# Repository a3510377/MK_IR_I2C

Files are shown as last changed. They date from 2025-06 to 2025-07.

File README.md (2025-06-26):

# MK_IR_I2C

基於 STM32F030F4P6 所設計的紅外線感測器陣列模組，具備 I2C 通訊能力，可快速整合至各類型機器人平台與自動化設備中。模組透過 CD74HC4067 多工器讀取 QRE1113GR 感測器，並將資料經 I2C 匯流排傳送至主控板（如 Arduino 或其他 MCU）。

## 🛠️ 硬體架構

- **MCU**：STM32F030F4P6
- **感測器**：16 顆 QRE1113GR 反射式紅外線感測器
- **類比多工器**：CD74HC4067
- **I²C 介面**：Slave 模式，支援標準與高速模式（100kHz / 400kHz）
- **輸出資料**：多通道反射值，單位為 8-bit 整數
- **擴充性**：
  - 支援多模組串接（透過不同 I²C 位址）
  - 每個感測器可單獨設定門檻值與使能狀態

## 📦 軟體功能

- I²C slave 實作，可接收主機命令與回傳感測資料
- 支援動態設定感測器參數（使能/閾值）
- 感測資料自動掃描（DMA + ADC）
- 內建 LED 狀態指示

## 📋 I²C 寄存器對照表（Register Map）

| 名稱 | 地址 | 權限 | 大小 | 說明 |
| --- | ---- | --- | --- | --- |
| `REG_LED` | 0x01 | R/W (CB) | 2 bytes  | 控制自訂 LED 狀態（16-bit），自動啟用自訂控制 |
| `REG_LED_MODE_MASK` | 0x02 | R/W | 2 bytes  | LED 控制遮罩，1=自訂控制，0=由閾值自動控制 |
| `REG_READ_THRESHOLD_ONE`  | 0x13 | R (CB) | 3 bytes  | 讀取單一通道閾值，格式：`[index] → [index][LSB][MSB]` |
| `REG_WRITE_THRESHOLD_ONE` | 0x14 | W (CB) | 3 bytes  | 寫入單一通道閾值，格式：`[index][LSB][MSB]` |
| `REG_THRESHOLD_ALL` | 0x15 | R/W (CB) | 32 bytes | 一次讀/寫全部 16 通道閾值，每通道 2 bytes |
| `REG_THRESHOLD_FLAG` | 0x16 | R | 2 bytes  | 閾值比較旗標（bitmask），1=超過，0=未超過 |
| `REG_ADC_DATA` | 0x29 | R | 32 bytes | 讀取所有通道 ADC 資料（16 通道 × 2 bytes） |
| `REG_ADC_DATA00` | 0x30 | R | 2 bytes  | 通道 0 的 ADC 數值 |
| `REG_ADC_DATA01` | 0x31 | R | 2 bytes  | 通道 1 的 ADC 數值 |
| `REG_ADC_DATA02` | 0x32 | R | 2 bytes  | 通道 2 的 ADC 數值 |
| `REG_ADC_DATA03` | 0x33 | R | 2 bytes  | 通道 3 的 ADC 數值 |
| `REG_ADC_DATA04` | 0x34 | R | 2 bytes  | 通道 4 的 ADC 數值 |
| `REG_ADC_DATA05` | 0x35 | R | 2 bytes  | 通道 5 的 ADC 數值 |
| `REG_ADC_DATA06` | 0x36 | R | 2 bytes  | 通道 6 的 ADC 數值 |
| `REG_ADC_DATA07` | 0x37 | R | 2 bytes  | 通道 7 的 ADC 數值 |
| `REG_ADC_DATA08` | 0x38 | R | 2 bytes  | 通道 8 的 ADC 數值 |
| `REG_ADC_DATA09` | 0x39 | R | 2 bytes  | 通道 9 的 ADC 數值 |
| `REG_ADC_DATA10` | 0x3A | R | 2 bytes  | 通道 10 的 ADC 數值 |
| `REG_ADC_DATA11` | 0x3B | R | 2 bytes  | 通道 11 的 ADC 數值 |
| `REG_ADC_DATA12` | 0x3C | R | 2 bytes  | 通道 12 的 ADC 數值 |
| `REG_ADC_DATA13` | 0x3D | R | 2 bytes  | 通道 13 的 ADC 數值 |
| `REG_ADC_DATA14` | 0x3E | R | 2 bytes  | 通道 14 的 ADC 數值 |
| `REG_ADC_DATA15` | 0x3F | R | 2 bytes  | 通道 15 的 ADC 數值 |
| `REG_VERSION` | 0xFE | R | 2 bytes  | 固件版本號（例如 `0x0102` 表示 v1.0.2） |
| `REG_LAST_ERROR` | 0xFF | R | 1 byte | 最後錯誤代碼（讀取後自動清除） |

> 💡 **說明**：
>
> - 權限欄位：`R` = Read、`W` = Write、`CB` = 透過 callback 處理邏輯。
> - 所有資料皆為小端序（Little Endian）。

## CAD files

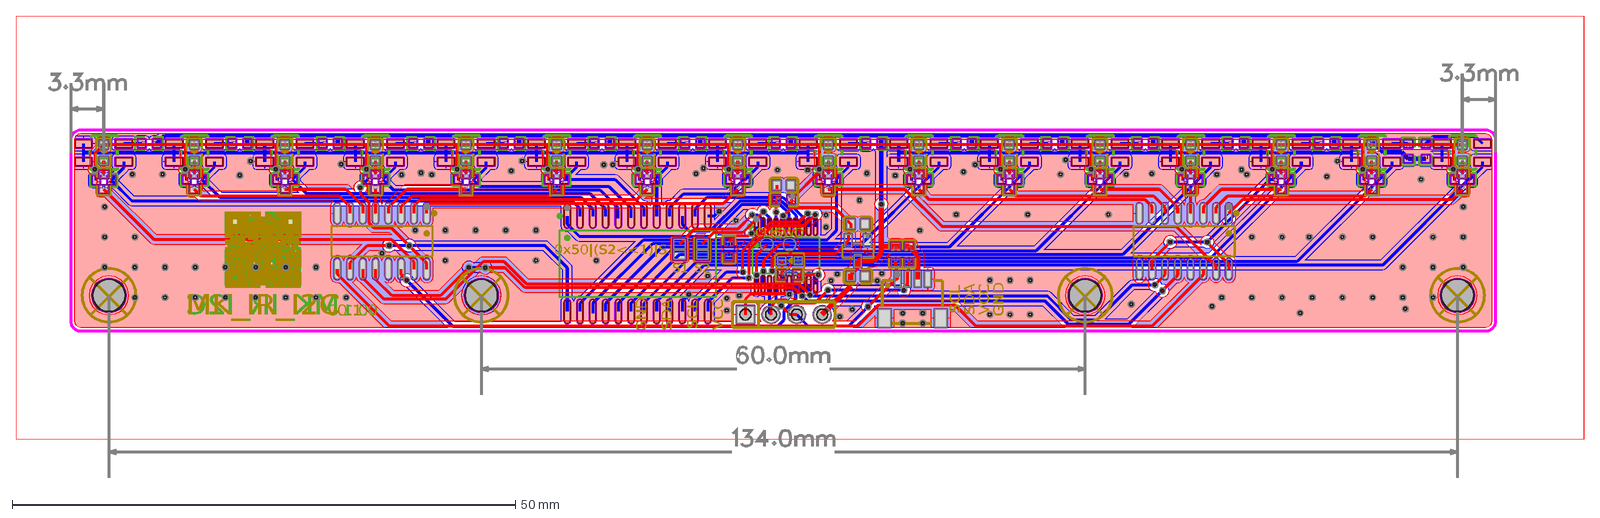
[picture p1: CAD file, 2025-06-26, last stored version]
docs/DXF_MK_IR_I2C_2025-06-17_AutoCAD2007.dxf
MK_IR_I2C
v0.1.0
GND
SDA
SCL
VCC
S2
S1
0x50|(S2<<1)|S1
CLK
SWD

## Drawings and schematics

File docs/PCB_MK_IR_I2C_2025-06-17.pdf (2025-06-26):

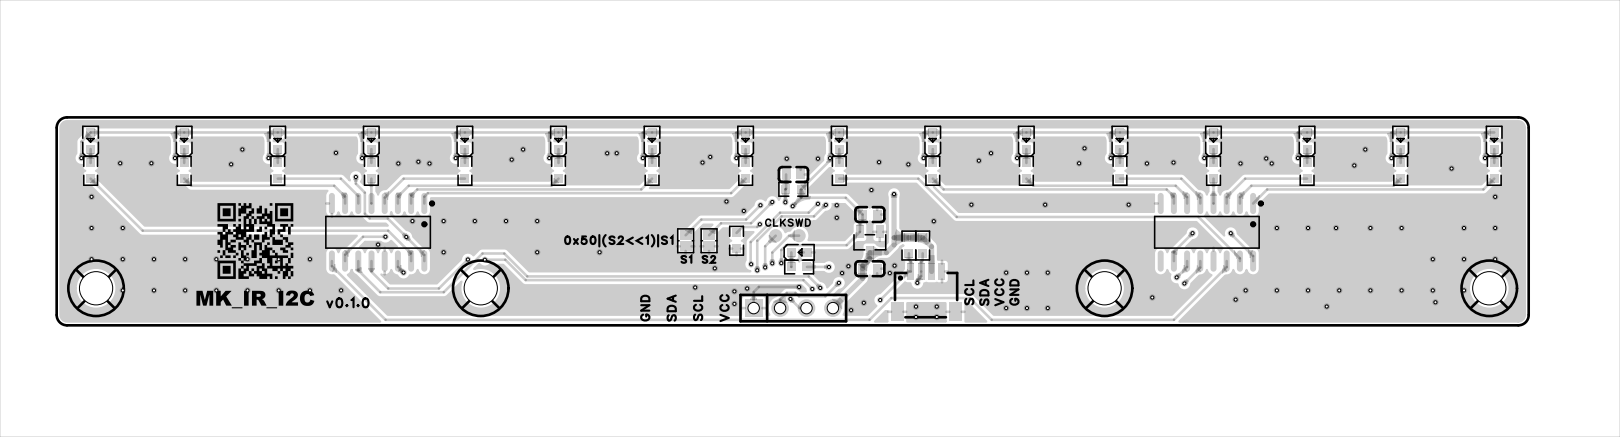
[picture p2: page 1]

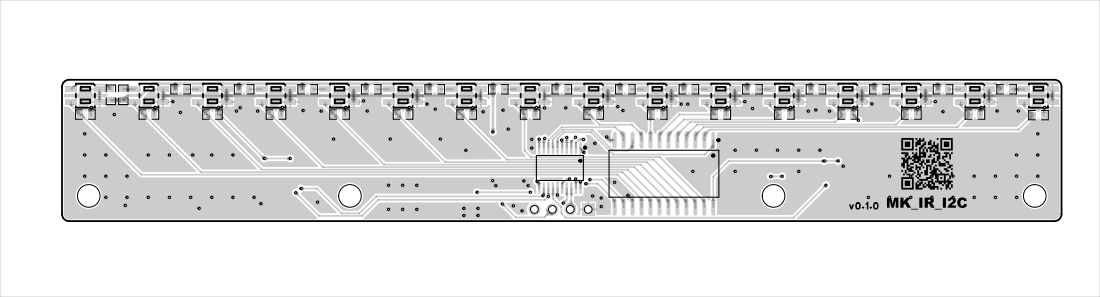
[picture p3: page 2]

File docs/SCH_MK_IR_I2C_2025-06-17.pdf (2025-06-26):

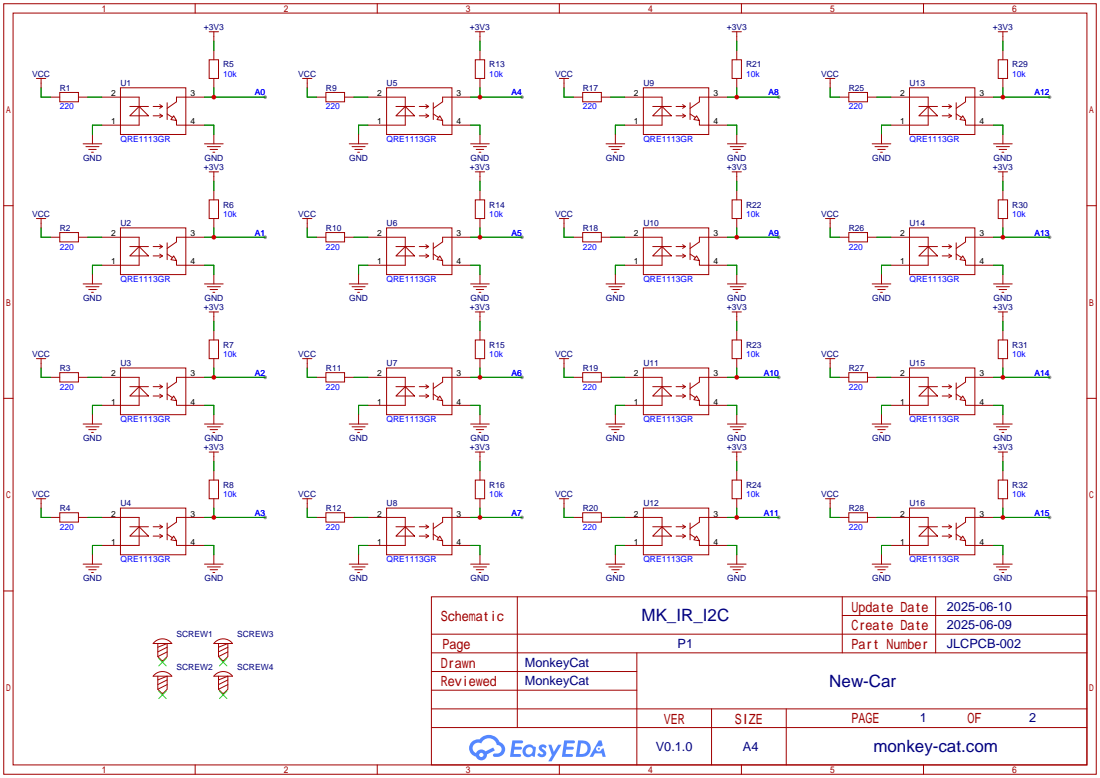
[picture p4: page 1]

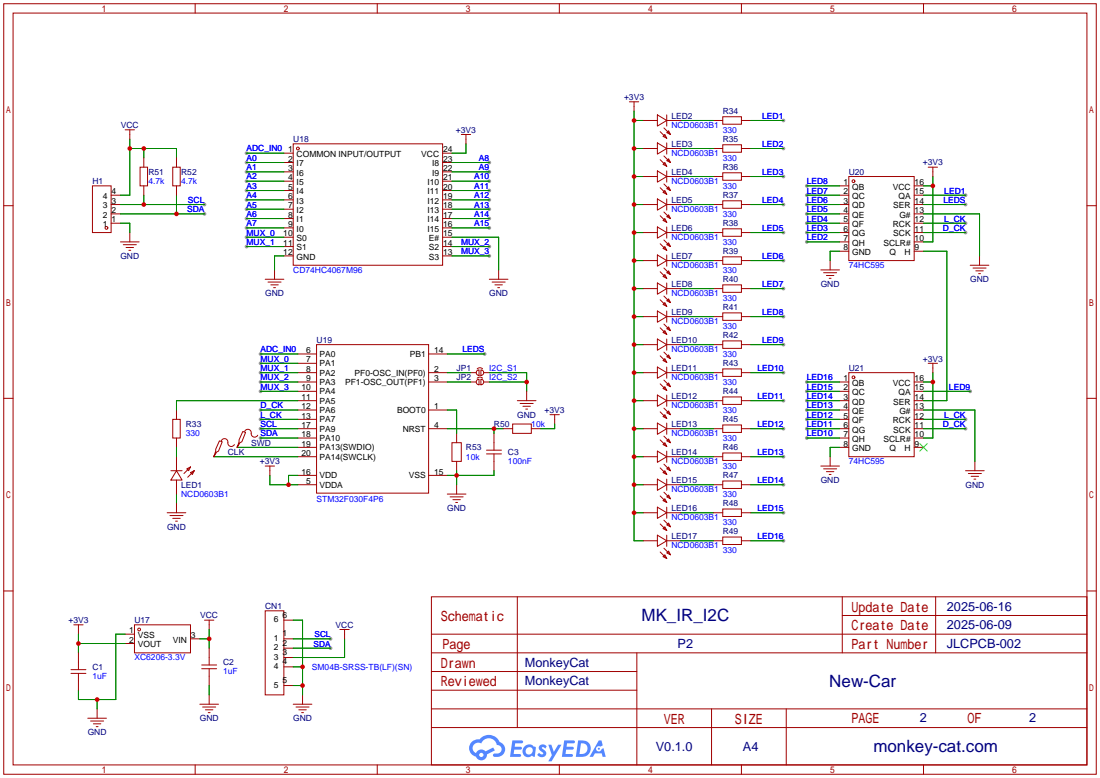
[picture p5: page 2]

SCLR# 10 SCK 11 RCK 12 G# 13 SER 14 QA 15 VCC 16

SM04B-SRSS-TB(LF)(SN)

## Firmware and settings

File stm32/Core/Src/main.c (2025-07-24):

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
/* Includes ------------------------------------------------------------------*/
#include "main.h"
#include "adc.h"
#include "dma.h"
#include "i2c.h"
#include "gpio.h"

/* USER CODE BEGIN Includes */
#include "i2c_slave.h"
#include "status.h"
/* USER CODE END Includes */

/* USER CODE BEGIN PD */
#define I2C_TX_BUF_SIZE 32
#define I2C_RX_BUF_SIZE 4
/* USER CODE END PD */

/* USER CODE BEGIN PM */
#define GPIO_SET(GPIOx, PinMask) ((GPIOx)->BSRR = (PinMask))
#define GPIO_CLR(GPIOx, PinMask) ((GPIOx)->BRR = (PinMask))
// #define GPIO_CLR(GPIOx, PinMask) ((GPIOx)->BSRR = ((uint32_t)(PinMask) <<
// 16))

/* USER CODE END PM */


void SystemClock_Config(void);
/* USER CODE BEGIN PFP */
void update_LED(void);
/* USER CODE END PFP */

/* USER CODE BEGIN 0 */
static int rx_busy_counter = 0;

volatile uint8_t last_error        = 0;
volatile uint16_t led_mode_mask    = 0;
volatile uint16_t custom_leds_data = 0;               // custom led value
volatile uint16_t threshold_flag   = 0;               // threshold result
volatile uint16_t thresholds[16]   = {0};             // led threshold
volatile uint16_t leds_data = 0, last_leds_data = 0;  // led value
volatile uint16_t mux_data[16] = {0};                 // adc value

volatile uint8_t mux_index       = 0;  // current mux index
volatile uint32_t adc_dma_buffer = 0;  // current adc value

static uint32_t last_update_time          = 0;
static volatile uint8_t updated_mux_index = 0;
/* USER CODE END 0 */

/**
 * @brief  The application entry point.
 * @retval int
 */
int main(void) {
  /* MCU Configuration--------------------------------------------------------*/

  /* Reset of all peripherals, Initializes the Flash interface and the Systick. */
  HAL_Init();

  /* Configure the system clock */
  SystemClock_Config();

  /* Initialize all configured peripherals */
  MX_GPIO_Init();
  MX_DMA_Init();
  MX_I2C1_Init();
  MX_ADC_Init();
  /* USER CODE BEGIN 2 */
  if (HAL_ADC_Start_DMA(&hadc, (uint32_t *)&adc_dma_buffer, 1) != HAL_OK) {
    Error_Handler();
  }
  if (I2C_begin() != HAL_OK) {
    Error_Handler();
  }

  update_LED();
  set_default_status();
  /* USER CODE END 2 */

  /* Infinite loop */
  /* USER CODE BEGIN WHILE */
  while (1) {
    uint32_t current_time = HAL_GetTick();
    if (current_time - last_update_time >= 1) {
      if (HAL_I2C_GetState(&hi2c1) == HAL_I2C_STATE_BUSY_RX_LISTEN) {
        rx_busy_counter++;

        if (rx_busy_counter > I2C_RX_BUSY_CNTR) {
          HAL_I2C_DisableListen_IT(&hi2c1);
          HAL_I2C_DeInit(&hi2c1);
          HAL_I2C_Init(&hi2c1);
          HAL_I2C_EnableListen_IT(&hi2c1);
          rx_busy_counter = 0;
        }
      } else rx_busy_counter = 0;

      if (last_leds_data != leds_data) {
        update_LED();
      }
    }

    if (mux_index == updated_mux_index) {
      mux_index = (mux_index + 1) % 16;

      // eq: GPIOA->BSRR = (0x0f << (16 + 1)) | ((mux_index & 0x0f) << 1);
      GPIOA->BSRR = 0x1e0000 | ((mux_index & 0x0f) << 1);

      for (int i = 0; i < 10; i++) __NOP();

      HAL_ADC_Start_DMA(&hadc, (uint32_t *)&adc_dma_buffer, 1);
    }

    update_status();
    /* USER CODE END WHILE */

    /* USER CODE BEGIN 3 */
  }
  /* USER CODE END 3 */
}

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
/* USER CODE BEGIN 4 */
void HAL_ADC_ConvCpltCallback(ADC_HandleTypeDef *hadc) {
  if (hadc->Instance == ADC1) {
    uint16_t value      = adc_dma_buffer;
    mux_data[mux_index] = value;

    uint16_t mask = 1 << mux_index;
    if (value > thresholds[mux_index]) threshold_flag |= mask;
    else threshold_flag &= ~mask;

    if (led_mode_mask & mask) {
      if (custom_leds_data & mask) leds_data |= mask;
      else leds_data &= ~mask;
    } else {
      if (threshold_flag & mask) leds_data |= mask;
      else leds_data &= ~mask;
    }

    updated_mux_index = mux_index;
  }
}

/** to display leds (HC595) */
void update_LED() {
  GPIO_CLR(L_CK_GPIO_Port, L_CK_Pin);
  for (uint8_t i = 0; i < 16; i++) {
    if (leds_data & (1 << i)) GPIO_SET(LEDS_GPIO_Port, LEDS_Pin);
    else GPIO_CLR(LEDS_GPIO_Port, LEDS_Pin);

    GPIO_SET(D_CK_GPIO_Port, D_CK_Pin);
    GPIO_CLR(D_CK_GPIO_Port, D_CK_Pin);
  }
  GPIO_SET(L_CK_GPIO_Port, L_CK_Pin);
  GPIO_CLR(L_CK_GPIO_Port, L_CK_Pin);

  last_leds_data = leds_data;
}
/* USER CODE END 4 */
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


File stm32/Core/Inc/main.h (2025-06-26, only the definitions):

#define I2C_S1_Pin GPIO_PIN_0
#define I2C_S1_GPIO_Port GPIOF
#define I2C_S2_Pin GPIO_PIN_1
#define I2C_S2_GPIO_Port GPIOF
#define MUX_0_Pin GPIO_PIN_1
#define MUX_0_GPIO_Port GPIOA
#define MUX_1_Pin GPIO_PIN_2
#define MUX_1_GPIO_Port GPIOA
#define MUX_2_Pin GPIO_PIN_3
#define MUX_2_GPIO_Port GPIOA
#define MUX_3_Pin GPIO_PIN_4
#define MUX_3_GPIO_Port GPIOA
#define STATUS_Pin GPIO_PIN_5
#define STATUS_GPIO_Port GPIOA
#define D_CK_Pin GPIO_PIN_6
#define D_CK_GPIO_Port GPIOA
#define L_CK_Pin GPIO_PIN_7
#define L_CK_GPIO_Port GPIOA
#define LEDS_Pin GPIO_PIN_1
#define LEDS_GPIO_Port GPIOB

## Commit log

2025-06-26 Update README with detailed hardware and register info
    Expanded the README to include a comprehensive description of the MK_IR_I2C module, its hardware architecture, software features, and a detailed I2C register map. This provides clearer guidance for i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
2025-06-26 Add callback for last_error register and refactor types
    Introduced a callback function for the last_error register to reset the error after reading. Refactored ValueType_t and reg_t struct formatting for consistency. Updated README to remove outdated note about LED and threshold data structure.
    [registers.c]
2025-06-26 feat i2c addr from S1 and S2
2025-06-27 change dir
    [DXF_MK_IR_I2C_2025-06-17_AutoCAD2007.dxf]
2025-07-24 Remove IWDG support and add MK_IR_I2C library
    Deleted IWDG-related source, headers, and driver files, and disabled HAL_IWDG in stm32f0xx_hal_conf.h. Added MK_IR_I2C Arduino library files, including source, headers, metadata, and workspace config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
    [DXF_MK_IR_I2C_2025-06-17_AutoCAD2007.dxf]
2025-07-24 Add latest PCB and schematic documentation
    Added new PDF and SVG files for PCB and schematic documentation of MK_IR_I2C as of 2025-06-17. These files provide updated hardware design references.

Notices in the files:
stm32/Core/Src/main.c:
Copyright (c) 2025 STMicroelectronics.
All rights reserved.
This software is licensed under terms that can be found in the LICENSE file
